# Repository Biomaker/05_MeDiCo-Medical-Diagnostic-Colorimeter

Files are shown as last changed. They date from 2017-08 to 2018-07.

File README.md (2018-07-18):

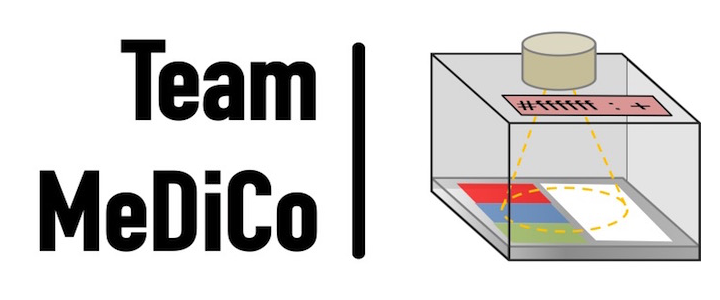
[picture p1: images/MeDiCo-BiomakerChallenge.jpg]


## Synopsis

This project will aim to develop a low-cost colorimeter to detect colour changes in medical diagnostic assays, such as those for infectious diseases. The system will be intended for use in resource poor settings with the aim of improving diagnostic accuracy and sensitivity by removing user subjectivity from the interpretation of the test result. The system will be open-source and take a range of sample types to allow it to be easily adaptable to a large variety of colorimetric diagnostic assays.  

## Team
Andrew Stretton and Cassi Henderson      
    
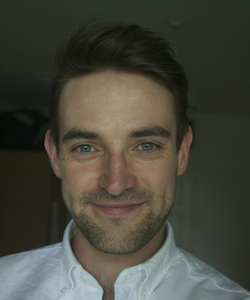
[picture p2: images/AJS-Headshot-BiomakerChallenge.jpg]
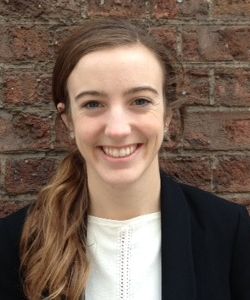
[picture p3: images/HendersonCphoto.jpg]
 

## Software

Explain functionality of software components (if any) as concisely as possible, developers should be able to figure out how your project solves their problem by looking at the code example. Ideally, this should be pseudo code or an abstract graphical representation of your code e.g entity relationship diagram. Consider adding a screenshot of your User Interface.

## Hardware

This device makes use of a Raspberry Pi 3 and a Pi Camera to take and process the images. A 3D printed box with sample loading drawer and several LEDs control the illumination of the sample. 

Assembly instructions:
1. Laser cut top.dxf from 3mm black PMMA.
2. Print box.stl and drawer.stl. We used PLA with 15% fill but adapt settings as needed for your printer.
3. Attach drawer handle through screw hole in center of drawer.
4. Fix 10 white LEDs in the 2 lines of holes in the top using Araldite Rapid. Allow to cure 24hr.
5. Attach Pi camera to center square hole in top. Attache camera to RaspPi as specified by manufacturer. Attach RaspPi to screen as specified by manufacturer.
6. Attach top to box using screws at each corner so Pi camera top is closest to the drawer opening.
7. Connect LEDs in parallel each with a ~200 Ohm resistor to a 9V battery. Insert a potentiometer into the circuit (see diagram).
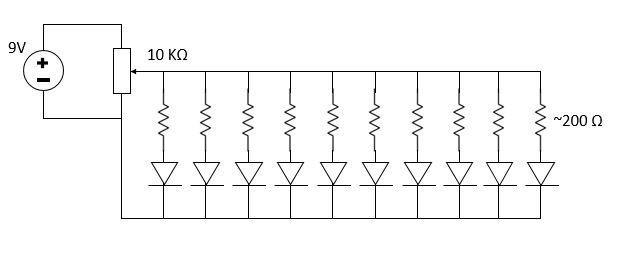
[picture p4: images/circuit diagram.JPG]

8. Adjust light with potentiometer to appropriate intensity. 

Assembled hardware (minus battery and Raspberry Pi/touchscreen connections)
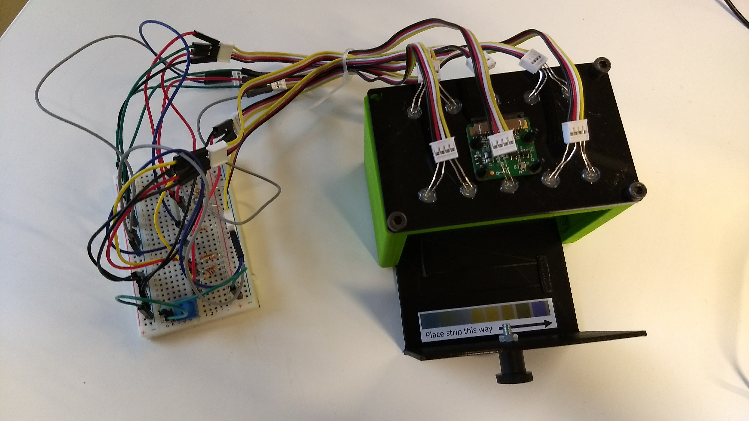
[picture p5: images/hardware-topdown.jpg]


## Installation, Maintenance and Testing Guide
This system can be adapted for a variety of test formats. The case study presented here is for multi-color pH strips. Summarized process flow diagram:

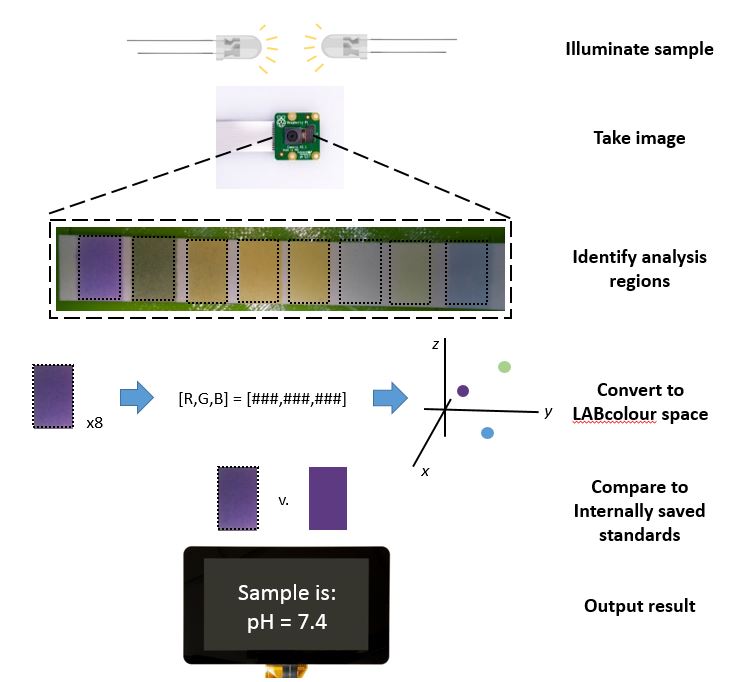
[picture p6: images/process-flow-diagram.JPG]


Instructions for use:
1. Power Raspberry Pi and camera through power bank and LEDs via the battery. 
2. Standards creation: Dip strip in solution of known pH. Load into drawer in sample slot. Run biomaker_camera.py to take image and process it to return LABspace color values for each color section. Save as part of analysis code as calibration value.
3. Sample testing: Dip strip in solution of known pH.  Load into drawer in sample slot. Run biomaker_camera.py to take image and process it to return pH value. 

## License

This code is released under the MIT License (http://opensource.org/licenses/MIT).

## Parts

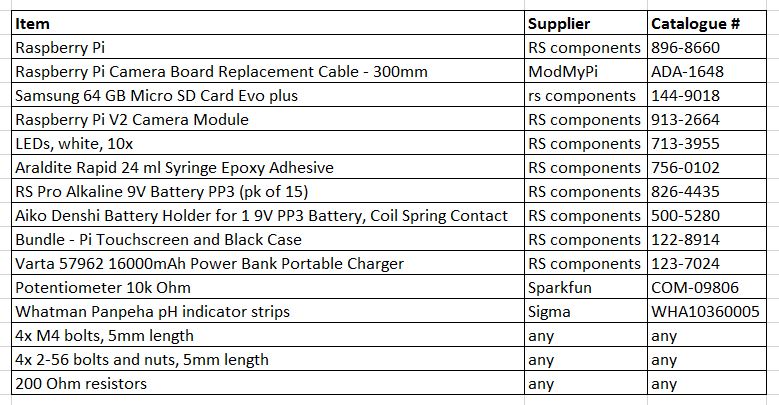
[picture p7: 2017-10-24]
Hardware/BOM.JPG

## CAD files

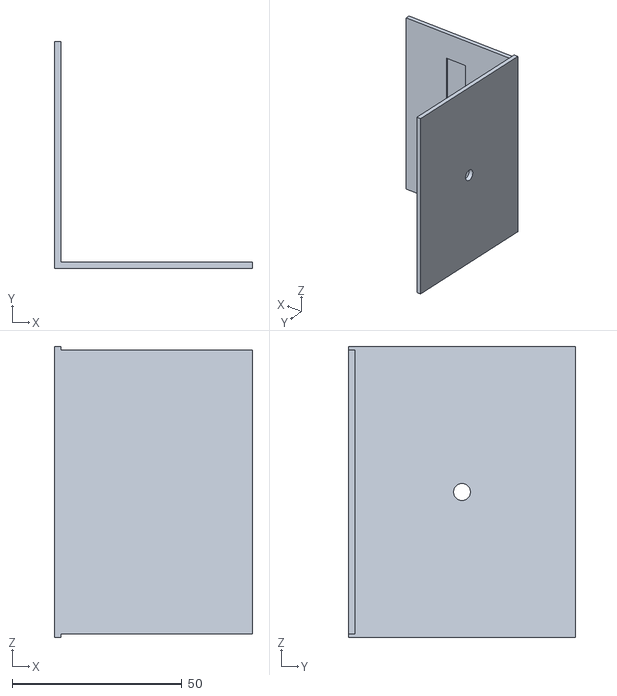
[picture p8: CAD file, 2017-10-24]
Hardware/drawer.stl
58.5 x 67.0 x 85.8

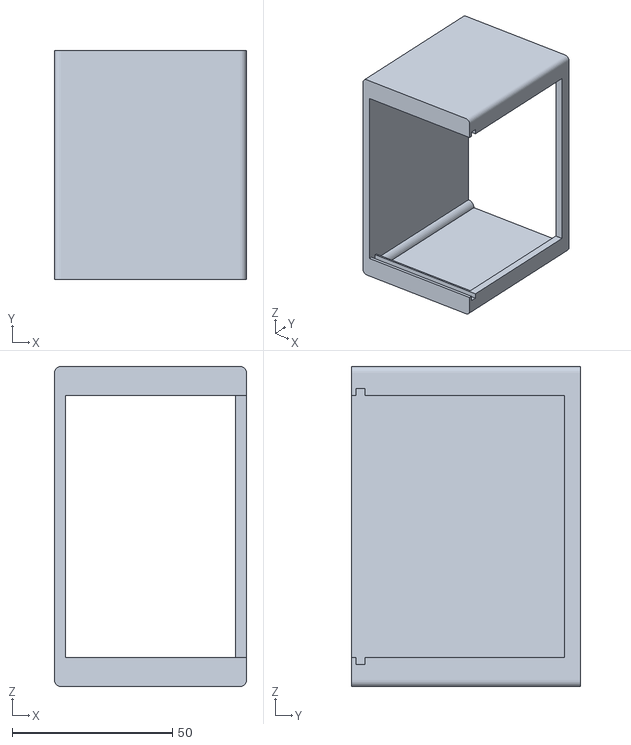
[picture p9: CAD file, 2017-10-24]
Hardware/box.stl
60.0 x 71.6 x 100.0

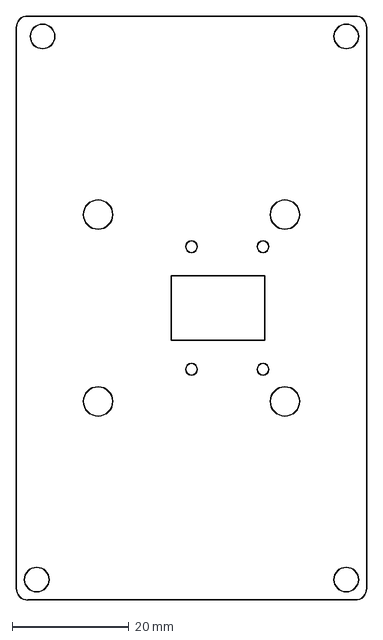
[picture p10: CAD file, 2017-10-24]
Hardware/top.dxf
60.0 x 100.0 mm

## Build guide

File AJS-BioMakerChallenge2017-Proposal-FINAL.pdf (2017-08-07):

# A low-cost colorimeter for accurate detection of colour changes in medical diagnostic tests

## Team

1) Andrew Stretton (primary contact), ajs309@cam.ac.uk, Sensor CDT & Chemical Engineering and Biotechnology (CEB)

Andrew’s background is in sensors and is currently working on a air quality device to selectively detect volatile organic compounds. He will primarily provide expertise and knowledge on sensor design and development. Andrew has worked on several optical sensing projects and will contribute skills and experience in electronics and device prototyping.

2) Cassi Henderson, cjh212@cam.ac.uk, CEB and Institute for Manufacturing (IfM)

Cassi’s background is in bioengineering and she is currently working on the development of the biological assay that the project will look to augment. She will contribute her expertise on the assay as well her knowledge of other colorimetric biosensors. She has also previously worked in medical device product development, so she brings skills in device requirement specification and project planning to support the project.

## Summary

This project will aim to develop a low-cost colorimeter to detect colour changes in medical diagnostic assays, such as those for infectious diseases. The system will be intended for use in resource poor settings with the aim of improving diagnostic accuracy and sensitivity by removing user subjectivity from the interpretation of the test result. The system will be open-source and take a range of sample types to allow it to be easily adaptable to a large variety of colorimetric diagnostic assays.

## Proposal

The Problem

Many diagnostic tests rely on the colour change of a sample to determine if a patient has a specific condition or disease. Often these colour changes are subtle, such as red to pink, and perception of a change is conditional on the subjectivity of the tester. These subtle colour changes are also a limitation in the sensitivity of colorimetric assays. These challenges are especially relevant in the case of resource limited settings, where laboratory facilities and trained personnel are in short supply and colorimetric assays are preferred for their ease of use. If it were possible to reliably generate a code to represent colour, such as a hex, this element of doubt would be removed and diagnostic accuracy and sensitivity would increase.

Biological Systems

Colour changes are used across the spectrum of biological systems used in diagnostic assays. The project will initially work with an assay being developed in the Cambridge Analytical Biosensors (CAB) lab that uses a pH sensitive dye to detect the production of double-stranded DNA for the detection of pathogenic leptospirosis. (Leptospirosis is a bacterial disease that is prevalent in low and middle income countries). In the future, the system could be adapted to work with other colorimetric biological assays, such as immunoassays with dye-labelled antibodies or enzymes that convert substrates into colour-producing products. Other assays are currently in development in the CAB lab on which the system could be trialled, time permitting.

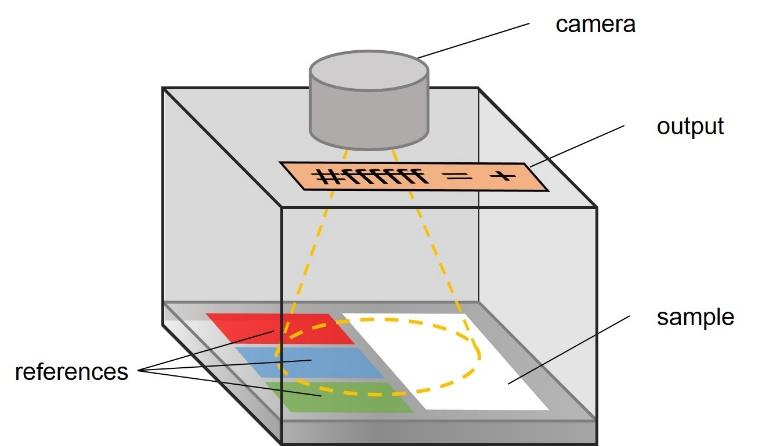
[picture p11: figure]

Design Goals

- The system should reliably produce a colour code for a range of biological samples that:
- Allows for differentiation between samples, e.g. positive/negative
- Remove subjectivity from interpretation
- To be applicable for use in a resource limited setting the system would need to be simple to print/produce, low-cost and run on battery power.

Plan to Implement the Project

Jul | Aug | Sep | Oct
Design basic hardware, i.e. housing, define focal length, define 1 sample input (vial, slide etc.)

2 Determine hardware optics - custom or smartphone

Develop code/software by generating hex codes from established 3 references

Extend code/software to generate hex codes for unknown colours 4 through reference comparison

Test hex code generation on biological samples and correlate 5 generated hex codes to positive/negative samples

Proposed Outcomes and Benefits

Outcomes:
- Functional prototype
- Tested on leptospirosis biosensor system
- Validation of concept for reliable colour change spotting

Benefits:
- Improved diagnostic accuracy/ sensitivity
- Faster biosensor development – less resource required to develop a completely subjectivity independent sensor

## Estimated Components

The majority of required components are included in the BioMaker Starter Kit. Other initial components are:

- | Raspberry Pi | RS Stock No. 896-8660 | £32.99
- | Power supply | RS Stock No. 909-8126 | £6.50
- | V2 Camera Module | RS Stock No.913-2664 | £20.99
- | White light source (LEDs) | RS Stock No.713-3955 | £2.58
- | Materials for housing: 3D printed (PLA) OR other plastic sheeting | ~£50
- | Biological consumables, e.g. nucleotides, enzymes, dyes (pH sensitive) | ~£100
- Miscellaneous
- | Colour References | RAL K7 colour fan deck, or similar | £15
- | Sample loading elements | Screws, metal sliders | ~£30
EST. TOTAL: | £258.06

Figure. Diagram of proposed device.

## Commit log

2017-10-24 added circuit diagram
2017-10-24 Create BOM
